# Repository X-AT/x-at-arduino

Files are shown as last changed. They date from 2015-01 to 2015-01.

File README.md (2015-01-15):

X Antenna Tracker arduino daughter board
========================================

This board implements simple and dumb controller
for low level devices like stepper driver and endstops.

All communication done by custom USB HID class.

[alpha version build on breadboard][blog]

[img171]: http://x-at.github.io/images/arduino-board/IMG171.jpg
[blog]: http://x-at.github.io/xat/2015/01/13/arduino-board.html

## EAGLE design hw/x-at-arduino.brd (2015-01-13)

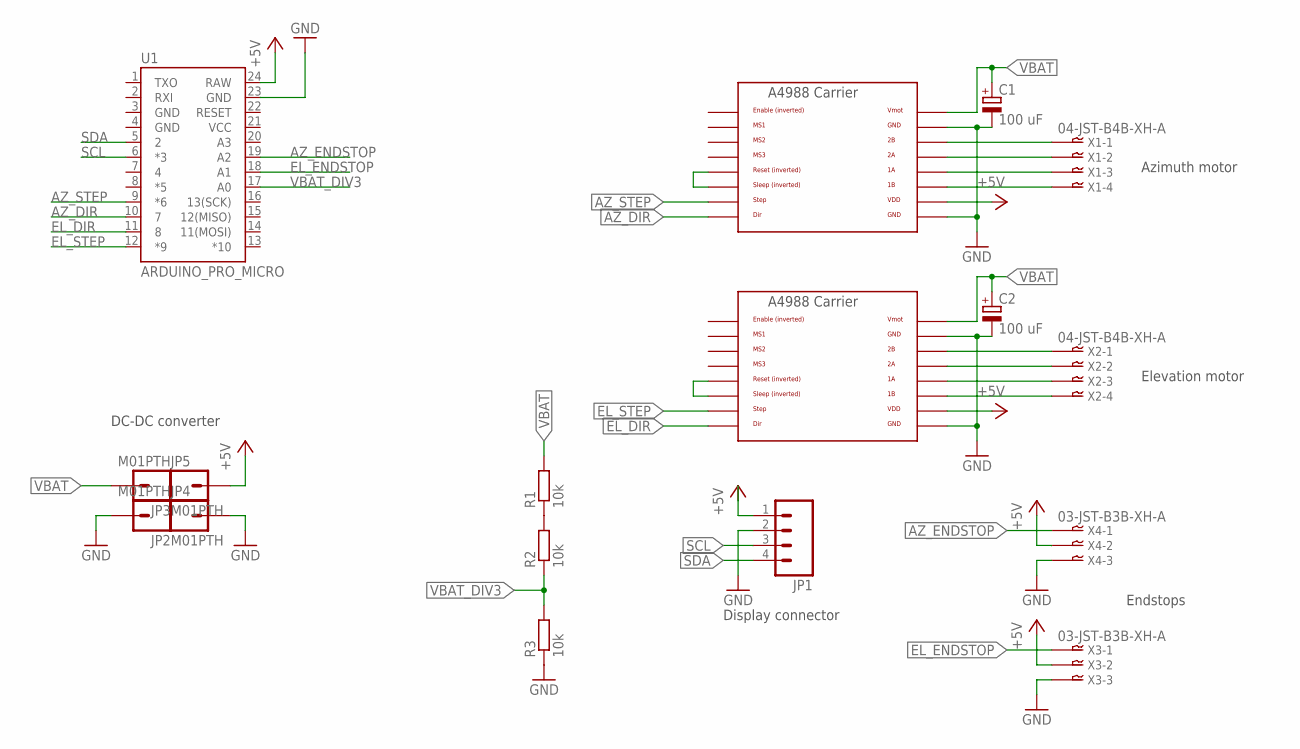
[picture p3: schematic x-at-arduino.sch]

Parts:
C1, C2: 100 uF; E5-6
JP1: M04PTH; 1X04
JP2, JP3, JP4, JP5: M01PTH; 1X01
R1, R2, R3: 10k; R0603
U1: ARDUINO_PRO_MICRO
U2, U3: POLOLU_A4983CARRIER; A4988BREAKOUT
X1, X2: 04-JST-B4B-XH-A; B4B-XH
X3, X4: 03-JST-B3B-XH-A; B3B-XH

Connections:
+5V: JP1.1, JP5.1, U1.24 (RAW), U2.VDD, U3.VDD, X3.P$2, X4.P$2
AZ_DIR: U1.10 (7), U2.DIR
AZ_ENDSTOP: U1.19 (A2), X4.P$1
AZ_STEP: U1.9 (*6), U2.STEP
EL_DIR: U1.11 (8), U3.DIR
EL_ENDSTOP: U1.18 (A1), X3.P$1
EL_STEP: U1.12 (*9), U3.STEP
GND: C1.-, C2.-, JP1.2, JP2.1, JP4.1, R3.1, U1.23 (GND), U2.GND, U2.GND@0 (GND), U3.GND, U3.GND@0 (GND), X3.P$3, X4.P$3
unnamed: U2.2B, X1.P$1
unnamed: U2.2A, X1.P$2
unnamed: U2.1A, X1.P$3
unnamed: U2.1B, X1.P$4
unnamed: U3.2B, X2.P$1
unnamed: U3.2A, X2.P$2
unnamed: U3.1A, X2.P$3
unnamed: U3.1B, X2.P$4
unnamed: R1.1, R2.2
unnamed: U3.RST, U3.SLP (SLEEP)
unnamed: U2.RST, U2.SLP (SLEEP)
SCL: JP1.3, U1.6 (*3)
SDA: JP1.4, U1.5 (2)
VBAT: C1.+, C2.+, JP3.1, R1.2, U2.VMOT, U3.VMOT
VBAT_DIV3: R2.1, R3.2, U1.17 (A0)

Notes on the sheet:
Display connector
Endstops
Azimuth motor
Elevation motor
DC-DC converter

Board: 2 copper layers, 17 parts (0 on the bottom side), 23 nets, no tracks yet.

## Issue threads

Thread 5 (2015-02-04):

Disable motor drivers if no movements.

vooon, 2015-02-04:
Copy SatNOGS feauture -> disable stepper drivers if there no moves more than T.

Require hw mod.

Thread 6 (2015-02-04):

Replace QTR-1A with optocupler sensors.

vooon, 2015-02-04:
With QTR homing not accurate.

vooon, 2015-02-04:
Alternative: Hall effect sensors, e.g. *SS441*.

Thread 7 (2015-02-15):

Possible bug in accel stepper port

vooon, 2015-02-15:
Strange skew on acceleration and deceleration. Not accurate rotation.

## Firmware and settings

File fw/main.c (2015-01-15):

/* @brief X-AT Arduino main
 * @file
 *
 * Based on LUFA GenericHID demo.
 */

#include "main.h"
#include "version.h"


static XAT_ReportBuffer_t prev_hid_report_buffer;
USB_ClassInfo_HID_Device_t xat_hid_interface = {
	.Config = {
		.InterfaceNumber              = INTERFACE_ID_XAT_HID,
		.ReportINEndpoint             = {
			.Address              = HID_IN_EPADDR,
			.Size                 = HID_EPSIZE,
			.Banks                = 1,
		},
		.PrevReportINBuffer           = prev_hid_report_buffer.data,
		.PrevReportINBufferSize       = sizeof(prev_hid_report_buffer),
	},
};

#define LED1_NORMAL	500
#define LED1_ERROR	100
static uint16_t led1_toggle_timeout = LED1_NORMAL;

static inline void alert_error(void) { led1_toggle_timeout = LED1_ERROR; }
static inline void alert_normal(void) { led1_toggle_timeout = LED1_NORMAL; }

static void setup_hardware(void)
{
	/* Disable watchdog if enabled by bootloader/fuses */
	MCUSR &= ~(1 << WDRF);
	wdt_disable();

	/* Disable clock division */
	clock_prescale_set(clock_div_1);

	/* Hardware Initialization */
	LEDs_Init();
	USB_Init();
	WallTime_Init();
	ADC_Task_Init();
	Stepper_Task_Init();

	/* Reenable wdr again */
	wdt_enable(WDTO_1S);
}

static uint16_t report_fill_info(XAT_ReportBuffer_t *data)
{
	strlcpy_P(data->info.device_caps, PSTR(DEVICE_CAPS), 60);
	return sizeof(data->info);
}

static uint16_t report_fill_status(XAT_ReportBuffer_t *data)
{
	data->status.flags = Stepper_GetFlags();
	data->status.buttons = QTR_GetStatusButtons();
	data->status.azimuth_position = Stepper_GetAzPosition();
	data->status.elevation_position = Stepper_GetElPosition();
	return sizeof(data->status);
}

static uint16_t report_fill_bat_voltage(XAT_ReportBuffer_t *data)
{
	data->bat_voltage.raw_adc = BAT_GetVoltageRaw();
	return sizeof(data->bat_voltage);
}

static uint16_t report_fill_stepper_settings(XAT_ReportBuffer_t *data)
{
	Stepper_GetSettings(&data->stepper_settings);
	return sizeof(data->stepper_settings);
}

static uint16_t report_fill_qtr(XAT_ReportBuffer_t *data)
{
	data->qtr.azimuth_qtr_raw = QTR_GetAzValueRaw();
	data->qtr.elevation_qtr_raw = QTR_GetElValueRaw();
	return sizeof(data->qtr);
}

static void report_apply_stepper_settings(const XAT_ReportBuffer_t *data, uint16_t size)
{
	if (size != sizeof(struct XAT_Report_Stepper_Settings)) {
		alert_error();
		return;
	}

	Stepper_SetSettings(&data->stepper_settings);
}

static void report_apply_az_el(const XAT_ReportBuffer_t *data, uint16_t size)
{
	if (size != sizeof(struct XAT_Report_Az_El)) {
		alert_error();
		return;
	}

	Stepper_SetAzEl(&data->az_el);
}

static void report_apply_qtr(const XAT_ReportBuffer_t *data, uint16_t size)
{
	if (size != sizeof(struct XAT_Report_QTR)) {
		alert_error();
		return;
	}

	QTR_SetAzElLevel(data->qtr.azimuth_qtr_raw, data->qtr.elevation_qtr_raw);
}

static void report_apply_cur_position(const XAT_ReportBuffer_t *data, uint16_t size)
{
	if (size != sizeof(struct XAT_Report_Cur_Position)) {
		alert_error();
		return;
	}

	Stepper_SetCurPosition(&data->cur_position);
}

static void report_apply_stop(const XAT_ReportBuffer_t *data, uint16_t size)
{
	if (size != sizeof(struct XAT_Report_Stop)) {
		alert_error();
		return;
	}

	Stepper_Stop(data->stop.motor & STOP_MOTOR_AZ, data->stop.motor & STOP_MOTOR_EL);
}


int main(void)
{
	setup_hardware();

	LEDs_TurnOnLEDs(LEDS_LED1 | LEDS_LED2);
	GlobalInterruptEnable();

	uint32_t last_blink_ms = millis();
	for (;;)
	{
		wdt_reset();
		HID_Device_USBTask(&xat_hid_interface);
		USB_USBTask();
		ADC_Task();
		Stepper_Task();

		if (millis() - last_blink_ms > led1_toggle_timeout) {
			last_blink_ms = millis();
			LEDs_ToggleLEDs(LEDS_LED1);
		}
	}
}

void EVENT_USB_Device_Connect(void)
{
	// XXX: leds inverted on PRO MICRO
	LEDs_TurnOffLEDs(LEDS_LED2);
	alert_normal();
}

void EVENT_USB_Device_Disconnect(void)
{
	// XXX: leds inverted on PRO MICRO
	LEDs_TurnOnLEDs(LEDS_LED2);
}

void EVENT_USB_Device_ConfigurationChanged(void)
{
	bool ConfigSuccess = true;

	ConfigSuccess &= HID_Device_ConfigureEndpoints(&xat_hid_interface);

	USB_Device_EnableSOFEvents();
}

void EVENT_USB_Device_ControlRequest(void)
{
	HID_Device_ProcessControlRequest(&xat_hid_interface);
}

void EVENT_USB_Device_StartOfFrame(void)
{
	HID_Device_MillisecondElapsed(&xat_hid_interface);
}

/** HID class driver callback function for the creation of HID reports to the host.
 *
 *  \param[in]     HIDInterfaceInfo  Pointer to the HID class interface configuration structure being referenced
 *  \param[in,out] ReportID    Report ID requested by the host if non-zero, otherwise callback should set to the generated report ID
 *  \param[in]     ReportType  Type of the report to create, either HID_REPORT_ITEM_In or HID_REPORT_ITEM_Feature
 *  \param[out]    ReportData  Pointer to a buffer where the created report should be stored
 *  \param[out]    ReportSize  Number of bytes written in the report (or zero if no report is to be sent)
 *
 *  \return Boolean \c true to force the sending of the report, \c false to let the library determine if it needs to be sent
 */
bool CALLBACK_HID_Device_CreateHIDReport(USB_ClassInfo_HID_Device_t* const HIDInterfaceInfo,
                                         uint8_t* const ReportID,
                                         const uint8_t ReportType,
                                         void* ReportData,
                                         uint16_t* const ReportSize)
{
	switch (*ReportID) {
	case REPORT_ID_F_INFO:
		*ReportSize = report_fill_info(ReportData);
		break;

	case REPORT_ID_G_STATUS:
		*ReportSize = report_fill_status(ReportData);
		break;

	case REPORT_ID_G_BAT_VOLTAGE:
		*ReportSize = report_fill_bat_voltage(ReportData);
		break;

	case REPORT_ID_F_STEPPER_SETTINGS:
		*ReportSize = report_fill_stepper_settings(ReportData);
		break;

	case REPORT_ID_F_QTR:
		*ReportSize = report_fill_qtr(ReportData);
		break;

	default:
		*ReportSize = 0;
		break;
	}

	if (*ReportSize != 0)
		alert_normal();

	return false;
}

/** HID class driver callback function for the processing of HID reports from the host.
 *
 *  \param[in] HIDInterfaceInfo  Pointer to the HID class interface configuration structure being referenced
 *  \param[in] ReportID    Report ID of the received report from the host
 *  \param[in] ReportType  The type of report that the host has sent, either HID_REPORT_ITEM_Out or HID_REPORT_ITEM_Feature
 *  \param[in] ReportData  Pointer to a buffer where the received report has been stored
 *  \param[in] ReportSize  Size in bytes of the received HID report
 */
void CALLBACK_HID_Device_ProcessHIDReport(USB_ClassInfo_HID_Device_t* const HIDInterfaceInfo,
                                          const uint8_t ReportID,
                                          const uint8_t ReportType,
                                          const void* ReportData,
                                          const uint16_t ReportSize)
{
	switch (ReportID) {
	case REPORT_ID_F_STEPPER_SETTINGS:
		report_apply_stepper_settings(ReportData, ReportSize);
		break;

	case REPORT_ID_S_AZ_EL:
		report_apply_az_el(ReportData, ReportSize);
		break;

	case REPORT_ID_F_QTR:
		report_apply_qtr(ReportData, ReportSize);
		break;

	case REPORT_ID_F_CUR_POSITION:
		report_apply_cur_position(ReportData, ReportSize);
		break;

	case REPORT_ID_S_STOP:
		report_apply_stop(ReportData, ReportSize);
		break;

	default:
		break;
	}
}

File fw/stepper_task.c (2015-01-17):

#include "main.h"
#include "accelstepper.h"

#define EL_STEP		PB5
#define EL_DIR		PB4
#define AZ_STEP		PD7
#define AZ_DIR		PE6
#define step_pulse_delay()	_delay_us(1)

#define INIT_ACCEL	50
#define INIT_MSPEED	200

static AccelStepper_t azimuth_stepper,
		      elevation_stepper;

static void azimuth_step(AccelStepper_t *self)
{
	cbi(PORTD, AZ_STEP);

	if (self->direction == DIRECTION_CCW)
		sbi(PORTE, AZ_DIR);
	else
		cbi(PORTE, AZ_DIR);

	sbi(PORTD, AZ_STEP);
	step_pulse_delay();
	cbi(PORTD, AZ_STEP);
}

static void elevation_step(AccelStepper_t *self)
{
	cbi(PORTB, EL_STEP);

	if (self->direction == DIRECTION_CCW)
		sbi(PORTB, EL_DIR);
	else
		cbi(PORTB, EL_DIR);

	sbi(PORTB, EL_STEP);
	step_pulse_delay();
	cbi(PORTB, EL_STEP);
}

void Stepper_Task_Init(void)
{
	// GPIO setup
	cbi(PORTB, EL_STEP);
	cbi(PORTB, EL_DIR);
	sbi(DDRB, EL_STEP);
	sbi(DDRB, EL_DIR);

	cbi(PORTD, AZ_STEP);
	cbi(PORTE, AZ_DIR);
	sbi(DDRD, AZ_STEP);
	sbi(DDRE, AZ_DIR);

	AS_ObjectInit(&azimuth_stepper, azimuth_step);
	AS_ObjectInit(&elevation_stepper, elevation_step);

	AS_SetAcceleration(&azimuth_stepper, INIT_ACCEL);
	AS_SetAcceleration(&elevation_stepper, INIT_ACCEL);
	AS_SetMaxSpeed(&azimuth_stepper, INIT_MSPEED);
	AS_SetMaxSpeed(&elevation_stepper, INIT_MSPEED);
}

void Stepper_Task(void)
{
	AS_Run(&azimuth_stepper);
	AS_Run(&elevation_stepper);
}

int32_t Stepper_GetAzPosition(void)
{
	return AS_CurrentPosition(&azimuth_stepper);
}

int32_t Stepper_GetElPosition(void)
{
	return AS_CurrentPosition(&elevation_stepper);
}

uint8_t Stepper_GetFlags(void)
{
	uint8_t flags = 0;

	if (AS_DistanceToGo(&azimuth_stepper) != 0)
		flags |= FLAGS_AZ_IN_MOTION;

	if (AS_DistanceToGo(&elevation_stepper) != 0)
		flags |= FLAGS_EL_IN_MOTION;

	return flags;
}

void Stepper_GetSettings(struct XAT_Report_Stepper_Settings *settings)
{
	// Should i add accesor wrapper?
	settings->azimuth_acceleration = azimuth_stepper.acceleration;
	settings->elevation_acceleration = elevation_stepper.acceleration;
	settings->azimuth_max_speed = azimuth_stepper.max_speed;
	settings->elevation_max_speed = elevation_stepper.max_speed;
}

void Stepper_SetSettings(const struct XAT_Report_Stepper_Settings *settings)
{
	AS_SetAcceleration(&azimuth_stepper, settings->azimuth_acceleration);
	AS_SetMaxSpeed(&azimuth_stepper, settings->azimuth_max_speed);
	AS_SetAcceleration(&elevation_stepper, settings->elevation_acceleration);
	AS_SetMaxSpeed(&elevation_stepper, settings->elevation_max_speed);
}

void Stepper_SetAzEl(const struct XAT_Report_Az_El *az_el)
{
	AS_MoveTo(&azimuth_stepper, az_el->azimuth_position);
	AS_MoveTo(&elevation_stepper, az_el->elevation_position);
}

void Stepper_SetCurPosition(const struct XAT_Report_Cur_Position *cur_position)
{
	AS_SetCurrentPosition(&azimuth_stepper, cur_position->azimuth_position);
	AS_SetCurrentPosition(&elevation_stepper, cur_position->elevation_position);
}

void Stepper_Stop(bool az, bool el)
{
	if (az)
		AS_Stop(&azimuth_stepper);

	if (el)
		AS_Stop(&elevation_stepper);
}

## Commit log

2015-01-13 Import eagle files
    [x-at-arduino.brd, x-at-arduino.sch]
2015-01-14 fw: Add reports for stepper and qtr.
2015-01-14 fw: Enable BAT VOLTAGE report.
2015-01-14 fw: Enable QTR report.
    I decided to replace QTR-1RC with QTR-1A (replace capacitor->resistor).
    [Descriptors.h, adc_task.c, main.c]
2015-01-14 fw: Port AccelStepper to C. Not tested.
    TODO: monotonic microsecond timer.
2015-01-14 fw: Import wall_time module for micros()/millis().
2015-01-14 fw: Add stepper_task module. Not tested.
2015-01-14 fw: Enable stepper reports. tested.
    accelstepper.c works like a charm.
2015-01-15 fw: Enable WDT. Fix #2
    [main.c]
2015-01-15 fw: Add error indication on LED1.
    [main.c, stepper_task.c]
2015-01-15 fw: Add reports for setting position and stop motors
2015-01-15 fw: Add reports for display write 8, 16, 32 and 60 bytes.
    Issue #1
    [Descriptors.h, main.c]
2015-01-15 hw: Note that now used analog sensor on endstop.
2015-01-15 fw: Remove display support (breaks stepper).
    Close #1.
2015-01-15 fw: Release 0.2.0. All devices works.
2015-01-17 fw: Fix IN_MOTION flags.
    [stepper_task.c]
2015-01-29 Apply my new VID/PID pair, fix version string.
    Thank to OpenMoko Inc!
    [Descriptors.h]

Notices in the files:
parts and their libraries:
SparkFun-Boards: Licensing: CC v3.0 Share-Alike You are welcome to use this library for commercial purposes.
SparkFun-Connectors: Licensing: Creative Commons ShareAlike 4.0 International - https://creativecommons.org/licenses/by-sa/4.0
